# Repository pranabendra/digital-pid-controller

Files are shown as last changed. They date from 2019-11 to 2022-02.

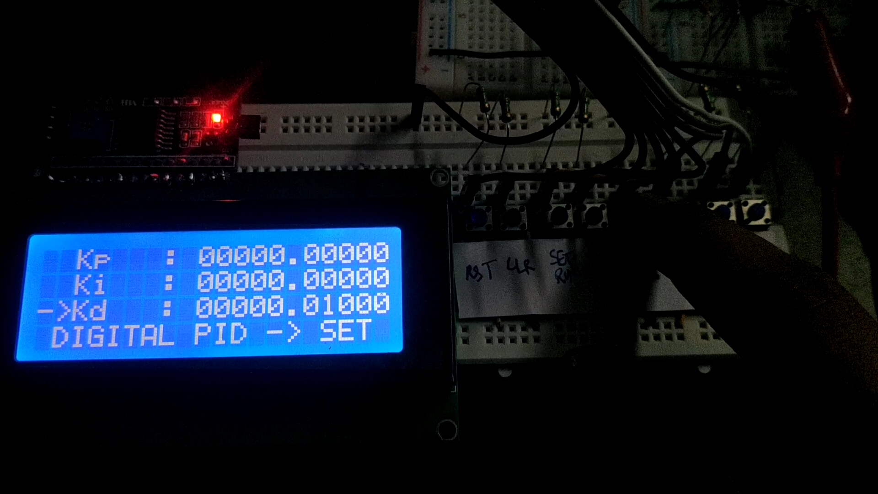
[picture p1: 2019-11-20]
Experiment Pictures/Screenshot_2019-11-15-21-35-13.jpg

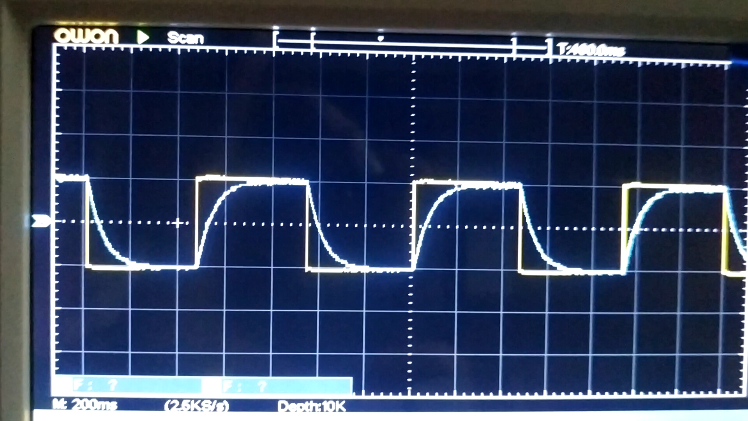
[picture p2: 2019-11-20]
Experiment Pictures/Screenshot_2019-11-15-23-25-31.jpg

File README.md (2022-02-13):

# Digital PID Controller for laboratory usage (Arduino based)

### Control Systems Seminar(I) Project 

<b>Project Title  :</b> Designing a PID controller having analog input and analog output, using digital and analog components for laboratory use

<b>Project Report :</b> [Link](https://github.com/pranabendra/digital-pid-controller/blob/master/Report/Control_Seminar_Project_PPC.pdf)

<b>Project Video  :</b> https://youtu.be/duWAQ8FL80s

---

### Published Paper

<b>Paper Title  :</b> A Framework for Digital PID Controller for Undergraduate Control Systems Laboratory Usage

<b>Paper Link   :</b> [DOI: 10.1109/INDICON52576.2021.9691674](https://doi.org/10.1109/INDICON52576.2021.9691674)

---

### Future work

Improvements can definitely be made to this framework, such as - 
1. A microcontroller having an in-built DAC (such as Arduino Due) can be used. This will eliminate the passive RC filter bank. But, we have to keep in mind that the current system is 5V tolerant. If we use a 3.3V tolerant microcontroller, the system needs a little re-design.
2. One SMPS with an inverting buck boost converter can be used instead of two SMPS. This is just to match the two power rails as close as possible in terms of DC level and ripple factor.
3. Anti-integral windup.
4. Anti-derivative kick. 

---

### Citation

```
@inproceedings{chandra2021framework,
  title={A Framework for Digital PID Controller for Undergraduate Control Systems Laboratory Usage},
  author={Chandra, Pranabendra Prasad},
  booktitle={2021 IEEE 18th India Council International Conference (INDICON)},
  pages={1--7},
  year={2021},
  organization={IEEE}
}
```

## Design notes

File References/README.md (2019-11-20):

# References

1.	Shinskey, F.G., 1979. Process control systems. McGraw-Hill, Inc.. 

2.	Johnson, C.D., 1999. Process control instrumentation technology. Prentice Hall PTR. 

3.	Boylestad, R.L. and Nashelsky, L., 2012. Electronic devices and circuit theory. Prentice Hall. 

4.	Carter, B. and Brown, T.R., 2001. Handbook of operational amplifier applications. Dallas, Tex, USA: Texas Instruments. 

5.	Shirriff, K. and Badger, P., 2009. Secrets of Arduino PWM. Ken Shirriff's Blog. 

6.	How to control a character I2C LCD with Arduino by Benne de Bakker, 
https://www.makerguides.com/character-i2c-lcd-arduino-tutorial/ 

7.	Wikipedia contributors, "PID controller," Wikipedia, The Free Encyclopedia, https://en.wikipedia.org/w/index.php?title=PID_controller&oldid=925590136 (accessed November 15, 2019). 

8.	Arduino Forum, “PWM Frequency Library”, https://forum.arduino.cc/index.php/topic,117425.0.html

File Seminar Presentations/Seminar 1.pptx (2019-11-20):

## Designing a PID controller with analog input and analog output signals using digital and analog components for laboratory use

Pranabendra Prasad Chandra
001610801122

## Block Diagram of a PID controller in a loop

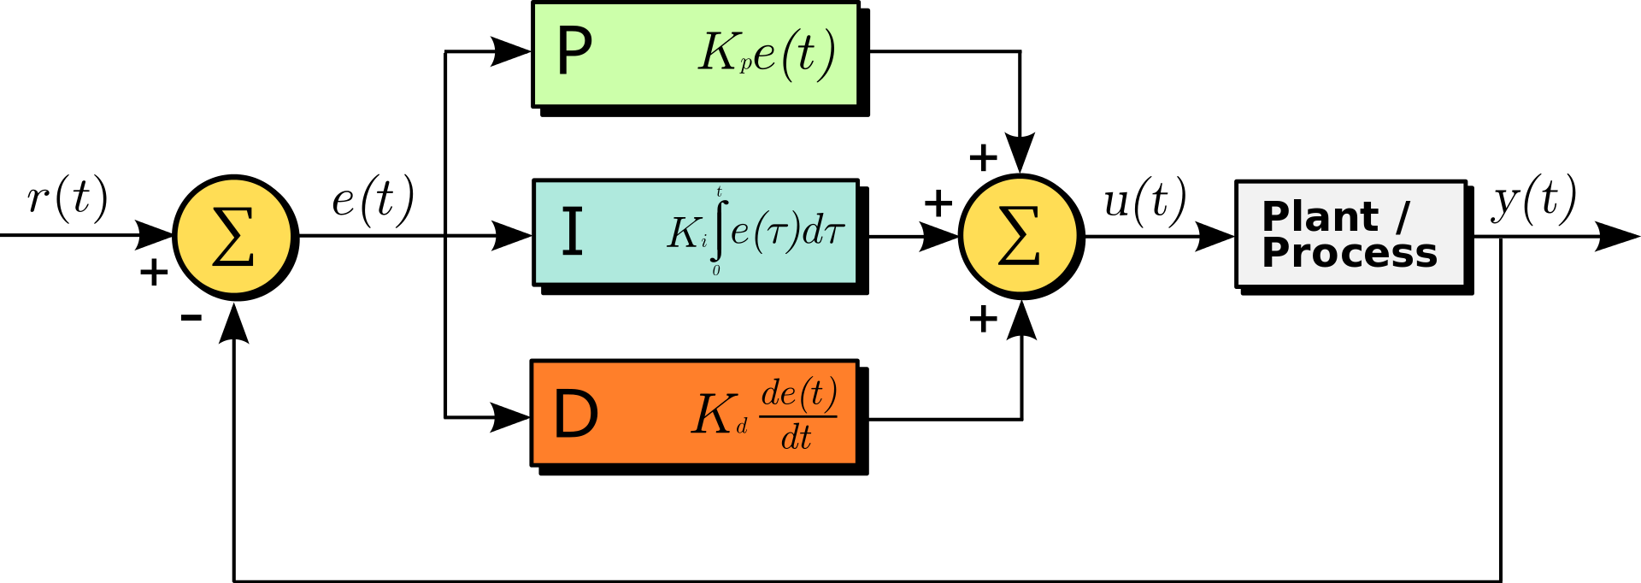
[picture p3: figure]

Image Source: PID Controller – Wikipedia (Link (https://en.wikipedia.org/wiki/PID_controller))

## PID Equation in Continuous Time

In continuous time domain, the PID equation is given as,
Where,
m(t) = controller output
e(t) = error signal

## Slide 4

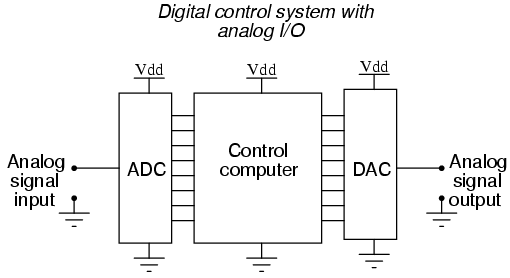
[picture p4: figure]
Image result for adc controller output

Image Source: DAC – All About Circuits (Link (https://www.allaboutcircuits.com/textbook/digital/chpt-13/digital-analog-conversion/))

## Digital Controller Equations

- Let the sampling frequency be fs
- Therefore, the sampling time becomes, τ = 1/ fs
- Replacing t by nτ , in discrete domain, the PID equation becomes

Trapezoidal Integration

Backward Difference

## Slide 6

## Design Specifications

- Maximum voltage input = 230V AC, ±340V DC
- Sampling frequency = Maximum 9 kHz in Arduino Uno (Will try ESP-32)

## Block Diagram

## Rectifier and Attenuator

## References

- Digital Controller Notes by Anjan Rakshit and Amitava Chatterjee
- Mohan, N., Undeland, T.M. and Robbins, W.P., 2003. Power electronics: converters, applications, and design. John wiley & sons.
- Shinskey, F.G., 1979. Process control systems. McGraw-Hill, Inc..

Tools used

Proteus 8 (Circuit Schematic Diagram)
Latex2PNG (Writing Equations)
Draw.io (Block Diagram)

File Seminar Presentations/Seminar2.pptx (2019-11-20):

## Designing a PID controller using analog input and analog output signals using digital and analog components for laboratory use

Pranabendra Prasad Chandra
001610801122

## Top View of the Controller

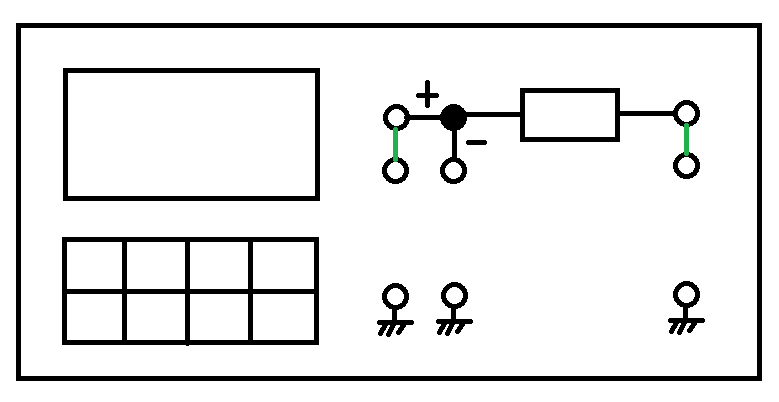
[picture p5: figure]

SET
POINT

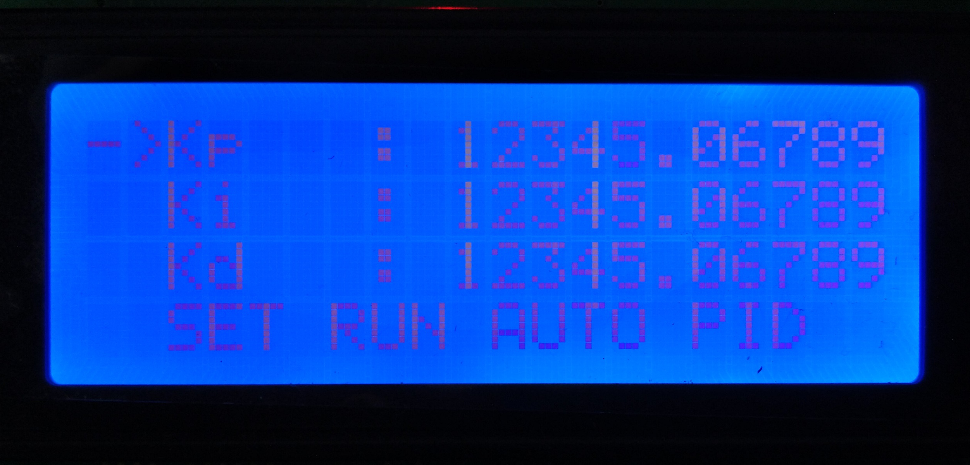
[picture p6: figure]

CONTROLLER

TO PLANT

SCOPE

FEEDBACK

SCOPE

## Block diagram of digital PID in hardware

## Simulation Result

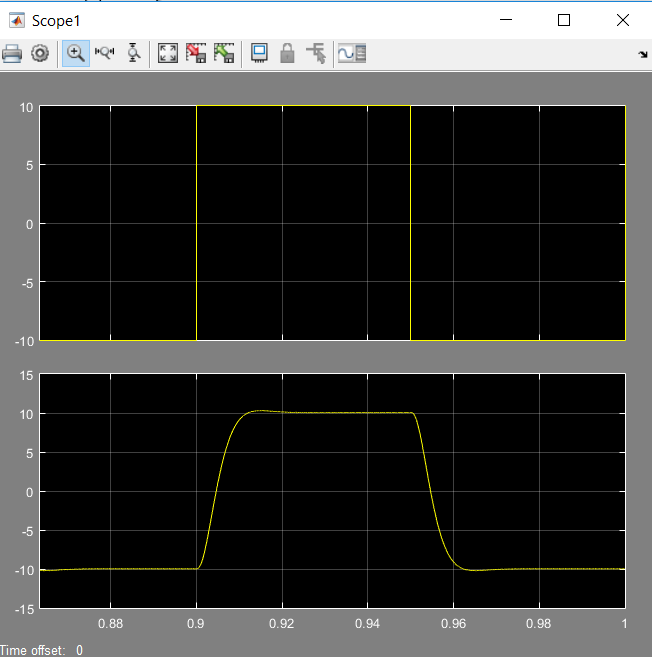
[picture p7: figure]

## Block diagram of digital PID in hardware

## Block diagram of digital PID in hardware

Signal Generator – 10 Vp-p (max)
Sine
Square
Triangle

## Block diagram of digital PID in hardware

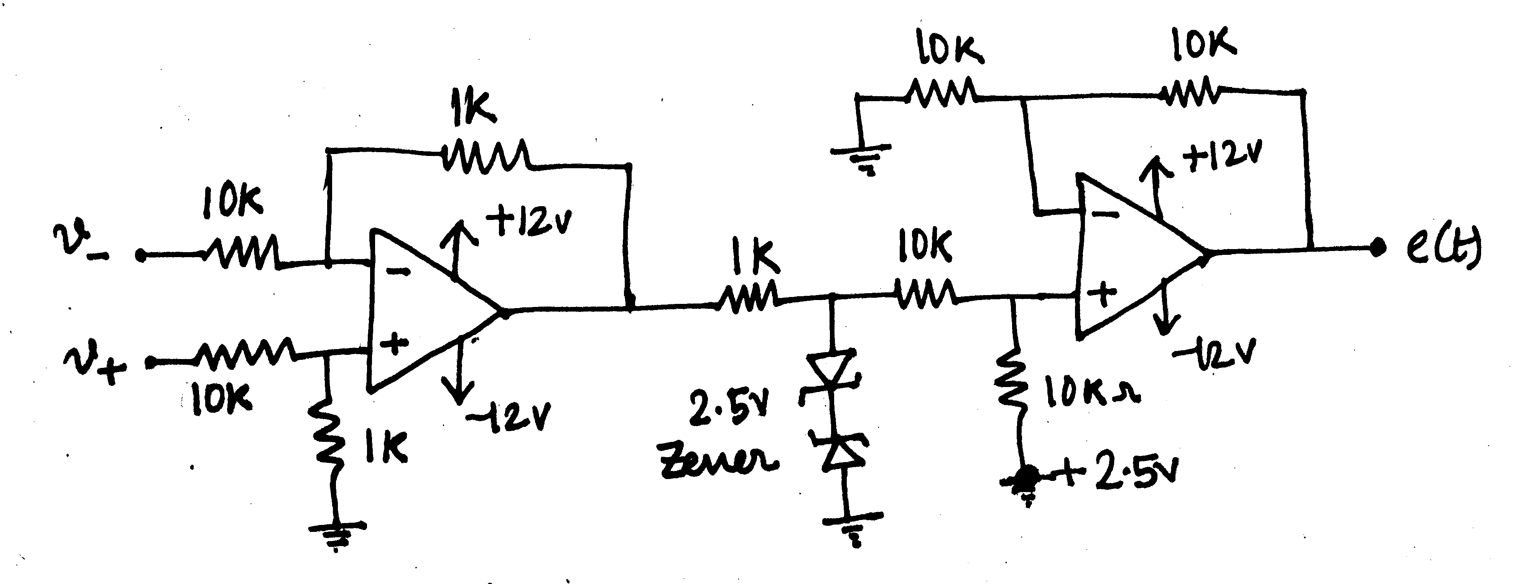
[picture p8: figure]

V- : 10 Vp-p
V+ : 10 Vp-p
e(t) : 0-5V
Op amp : OP07
2.5V Zener : 1N5222B

## Block diagram of digital PID in hardware

5V PWM

20x4 LCD

Keypad

Microcontroller : Arduino Mega
Voltage Input : 5V Regulated DC
Sampling Frequency : 5000 Hz (max 9 kHz)
PWM Switching Frequency : 5000 Hz

## Block diagram of digital PID in hardware

Low Pass Filter
Cut-off frequency should be less than the switching frequency
But, cut-off frequency should be high enough to pass the setpoint
Here, cut-off frequency is 160 Hz (tuneable)

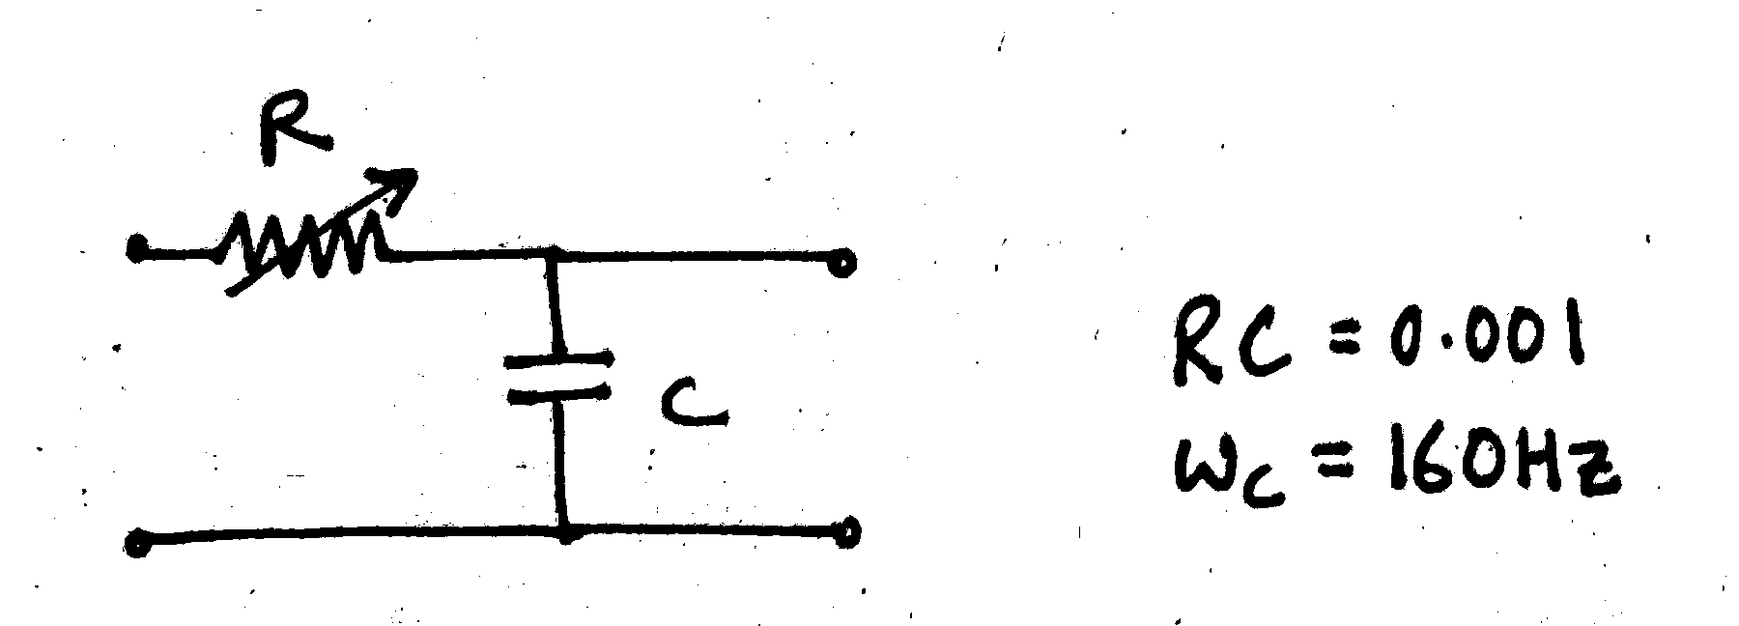
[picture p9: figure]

## Block diagram of digital PID in hardware

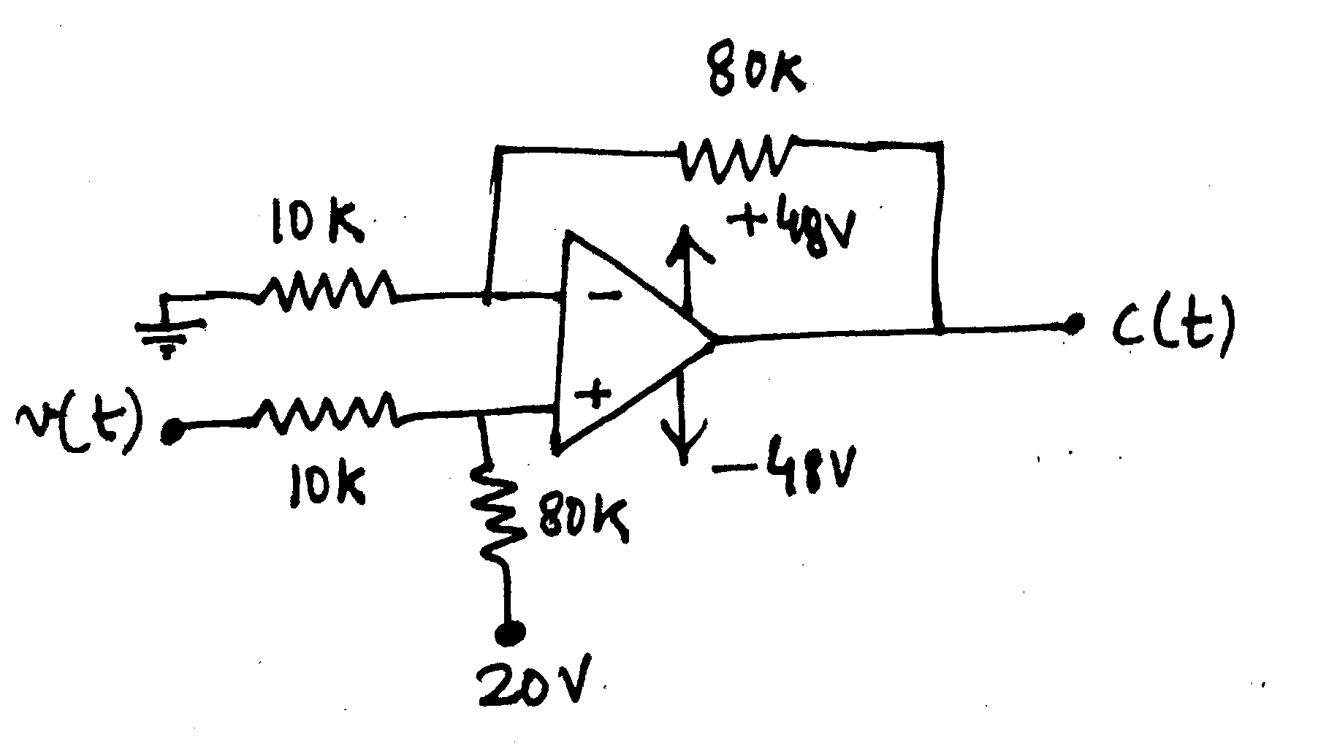
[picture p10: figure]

## Power Lines

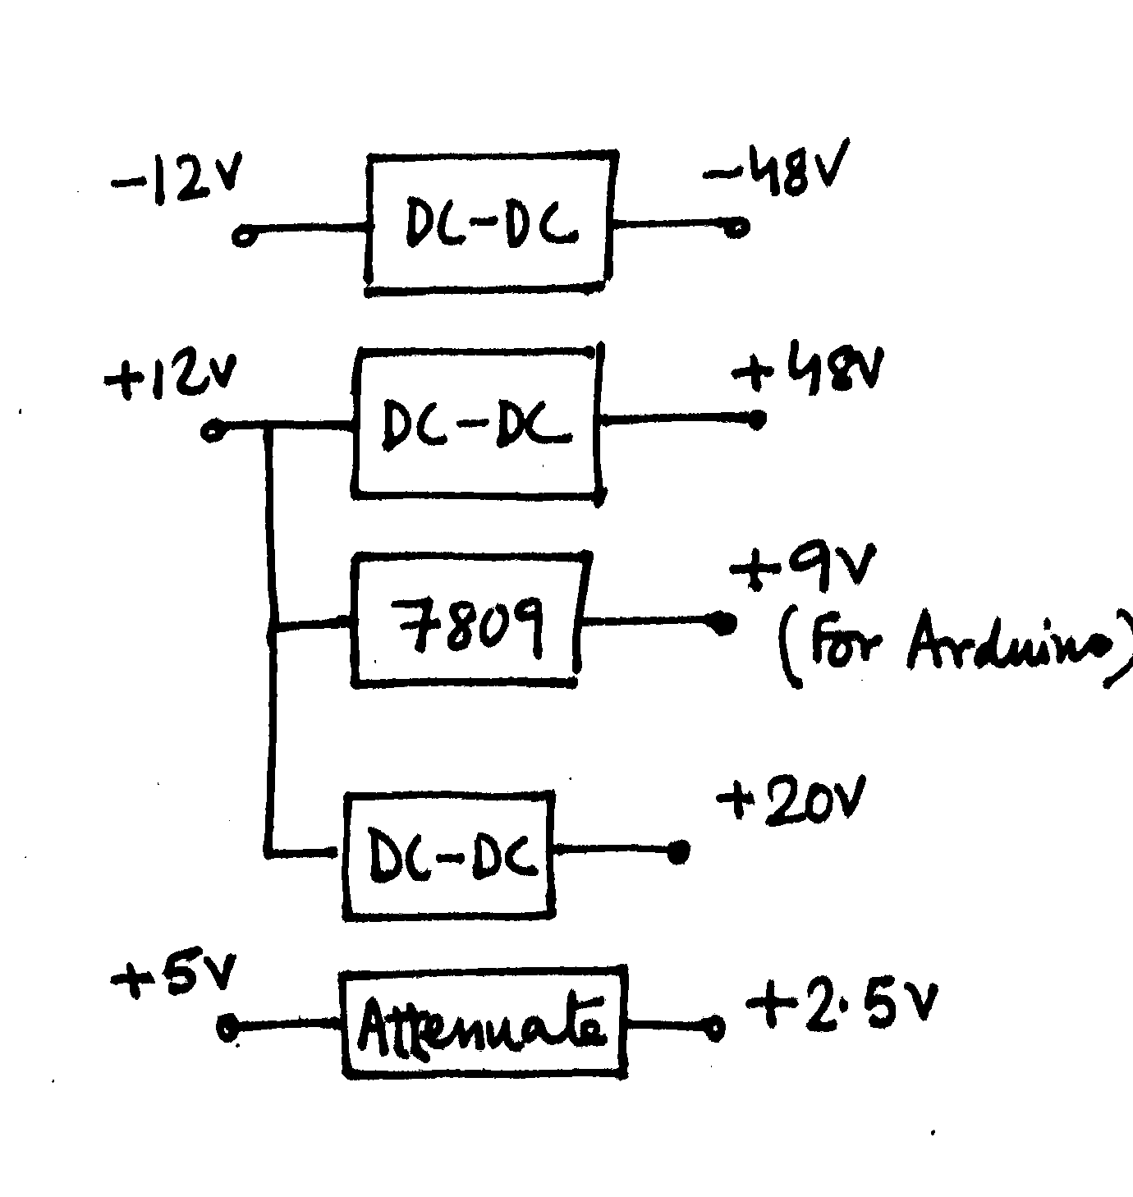
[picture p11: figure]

## Protection

- Risk

- Chance of pressing multiple buttons together
- Shorting the output
- Putting input signal in output port
- Overvoltage in mains
- Overcurrent from mains

- Remedy

- Latching the first button pressed
- Current limiting resistor
- Buffer
- P.T. + Relay
- C.T. + Relay

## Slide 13

## References

- Secrets of Arduino PWM (Link (https://www.arduino.cc/en/Tutorial/SecretsOfArduinoPWM))
- Basic Calculation of an Inverting Buck-Boost Power Stage – Texas Instruments (Link (http://www.ti.com/lit/an/slva721a/slva721a.pdf))

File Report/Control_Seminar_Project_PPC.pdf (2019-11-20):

# DESIGNING A PID CONTROLLER USING ANALOG INPUT AND ANALOG OUTPUT SIGNALS USING DIGITAL AND ANALOG COMPONENTS FOR LABORATORY USE

NOVEMBER 16, 2019
PRANABENDRA PRASAD CHANDRA BEE – IV, Section B2
Roll No. 001610801122

PRANABENDRA PRASAD CHANDRA, BEE-IV, SECTION B2, 001610801122 | 1

## Acknowledgement

The success and final outcome of this project required a lot of guidance and assistance from many people and I am extremely privileged to have got this all along the completion of my project. All that I have done, is only due to such supervision and assistance and I would not forget to thank them.

I wish to express my heartfelt gratitude to my parents, for their encouragement, moral support and care.

I am obliged and grateful to my professors Prof. T.K. Ghoshal, Prof. S. Bhattacharya and Prof.
S. Sadhu for providing me the opportunity to complete a project work on the topic ‘Designing a PID controller using analog input and analog output signals using digital and analog components for laboratory use’. I also wish to express my gratitude to them for their constant support and guidance throughout the work.

This project helped me to understand digital PID controller and its thorough functioning. It also provided me an opportunity for self-learning and know how both hardware and software play equally important rolesin the development of the product.

Also, I would like to extend my sincere thanks to all my classmates for their constant help throughout the work.

Pranabendra Prasad Chandra

PRANABENDRA PRASAD CHANDRA, BEE-IV, SECTION B2, 001610801122 | 2

## Contents

PRANABENDRA PRASAD CHANDRA, BEE-IV, SECTION B2, 001610801122 | 3

## ABSTRACT

Project Topic :

Designing a PID controller using analog input and analog output signals using digital and analog components for laboratory use

PID controllers can be used to regulate flow, temperature, pressure, level, and many other industrial process variables.

This project deals with the development of a digital PID controller for laboratory use. The controller takes in analog signal input, does the computations digitally and then outputs analog signal for the plant. The user operating this controller, can see the PID gains and adjust them as desired. Protections like overvoltage protection and latching of inputs have been incorporated, as a safety measure.

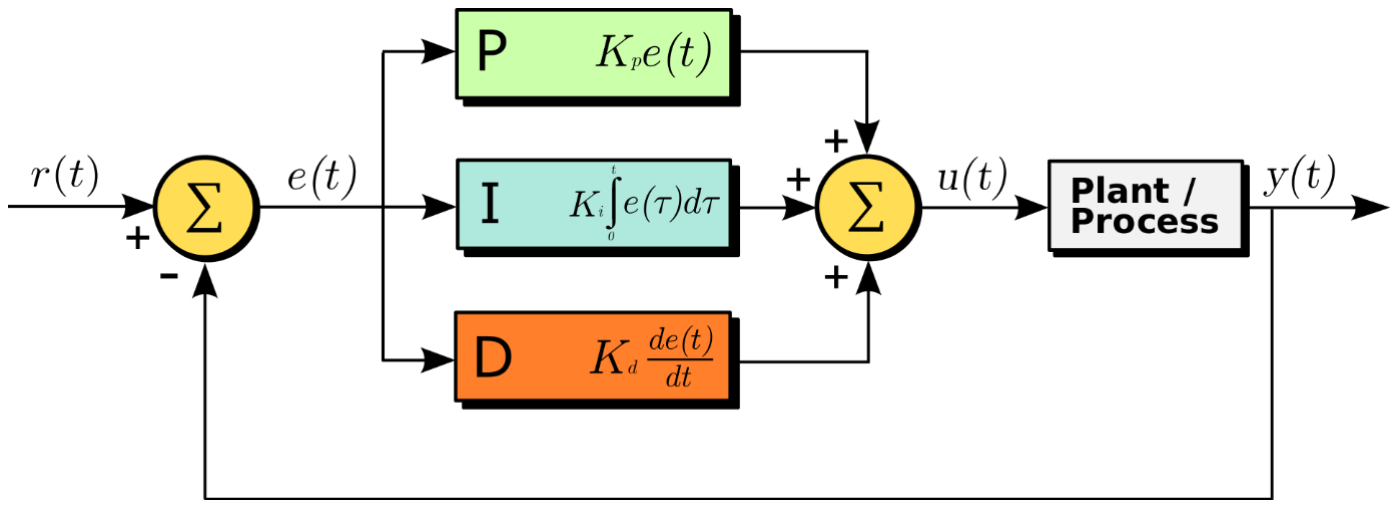
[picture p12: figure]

PRANABENDRA PRASAD CHANDRA, BEE-IV, SECTION B2, 001610801122 | 4

## PID Controller

A PID controller calculates an error value e as the difference between a desired setpoint r and a measured process variable y. It then applies a correction based on the proportional, integral, and derivative terms. Hence, it enables automatic control.

^ Image source: “PID controller overview” by Arturo Urquizo, PID Controller - Wikipedia

PID in continuous-time domain
In continuous time domain, the PID equation is given as,

u(t) = Kpe(t) + Ki ∫ e(τ)dτ

t

0

+ Kd

d
dt e(t)

where,

- e(t) is controller input
- u(t) is controller output
- Kp is proportional gain
- Ki

is integral gain
- Kd is derivative gain

In Laplace domain, the PID operation can be represented as,

e(t) | u(t)
PID(s)

PRANABENDRA PRASAD CHANDRA, BEE-IV, SECTION B2, 001610801122 | 5

PID in discrete-time domain

Let, the sampling frequency be fs

∴ Sampling time period = Ts = 1/fs

Discretizing the continuous time domain PID equation,

u(t) = Kpe(t) + Ki ∫ e(τ)dτ

t

0

+ Kd

d
dt e(t)

un = Kpen + KiTs∑ ej

n−1

j=0

+

Kd
Ts

(en − en−1)

Since we have tried to simulate the digital PID controller in Simulink first, we have followed the transfer function offered by Simulink, all throughout the project.

The Discrete PID Controller block in Simulink, MATLAB has the transfer function,

U(z)
E(z)

= Kp + KiTs

1
z − 1

+ Kd

N

1 + NTs

1
z − 1

Converting this transfer into difference equations, we obtain,

- un
(1) = Kp en
- un
(2) = un−1
(2) + KiTsen−1
- un
(3) = un−1

(3)
(1 − NTs

) + DN(en − en−1

)

Summing these three difference equations, the controller output becomes

un = un

(1) + un
(2) + un

(3)

The filter coefficient N in the above transfer function implements derivative action, by forming a proper transfer function. If N is sufficiently large, the derivative term will tend to

Kd
Ts

(z − 1)

en | un
PID(z)
A/D Converter | D/A Converter
e(t) | u(t)

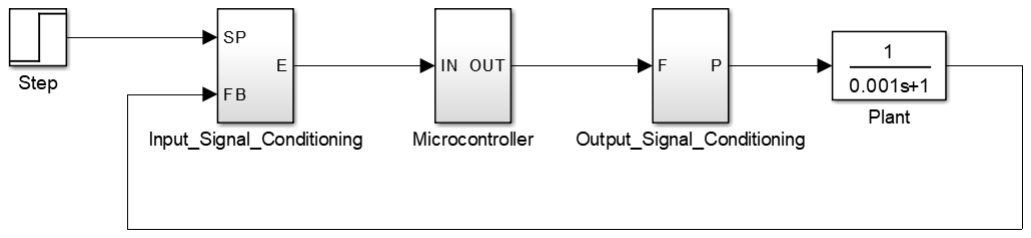
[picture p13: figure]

PRANABENDRA PRASAD CHANDRA, BEE-IV, SECTION B2, 001610801122 | 6

## Implementation

Controller Specifications
Supply voltage +12V and -12V (generated using two SMPS)

Voltage of input signal and feedback should be within +10V to -10V

Sampling frequency = 5000 Hz

PWM switching frequency = 100 kHz
Block Diagram and Simulation in Simulink
SP | : | Set Point
FB | : | Feedback (Plant Output)
E | : | Modified Error
IN | : | Microcontroller Signal Input
OUT | : | Microcontroller Signal Output (PWM)
F | : | Filter Input
P | : | Plant Input (Controller Output)

Input Signal Conditioning
As mentioned in the controller specifications, | −10V ≤ VSP,VFB ≤ 10V
Hence, | −20V ≤ (VSP − VFB) ≤ 20V

Modified error E =

VSP−VFB
10

+ 2.5V

Therefore, 0.5V ≤ E ≤ 4.5V

This bound of E ensures that the ADC of the microcontroller does not get damaged, as it can only take positive voltages less than or equal to 5V.

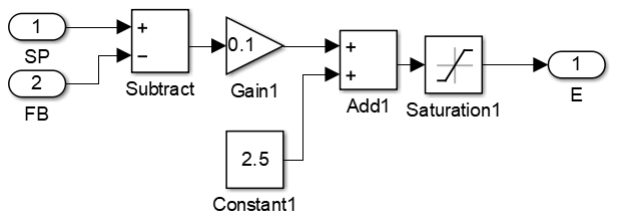
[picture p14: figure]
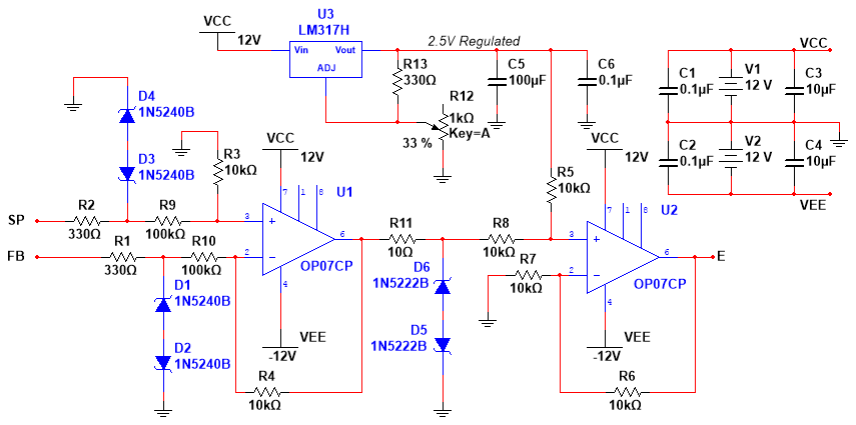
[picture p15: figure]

PRANABENDRA PRASAD CHANDRA, BEE-IV, SECTION B2, 001610801122 | 7

Circuit Realisation

- U1 and U2 are precision op-amps, having very low offset voltage, in the order of microvolts.
- U1 acts as a differential amplifier having gain 0.1 to attenuate (VSP – VFB) by 10 times. D1 and D2 are used in back-to-back mode for overvoltage protection. Their breakdown voltage is 10V. This ensures that the signal passing through to R10 remains within +10V and -10V. Else, the Zener diodes clips the voltage. R1 is used as a current limiting resistance, to protect D1 and D2 from overcurrent. Similar is the case for D3, D4, R2 and R9.
- D5 and D6 have breakdown voltage of 2.5V. They function similarly, to keep the signal within the limits of -2.5V to +2.5V.
- U3 is an adjustable positive voltage regulator. R12 is adjusted finely, to set the output regulated voltage to 2.5V.
- U2 acts as a non-inverting adder, with gain 1. It generates an offset of 2.5V to the bipolar signal, to make it a unipolar signal (lying between 0V to 5V).
- All the capacitors used in the above circuit, are decoupling capacitors used with voltage supplies.

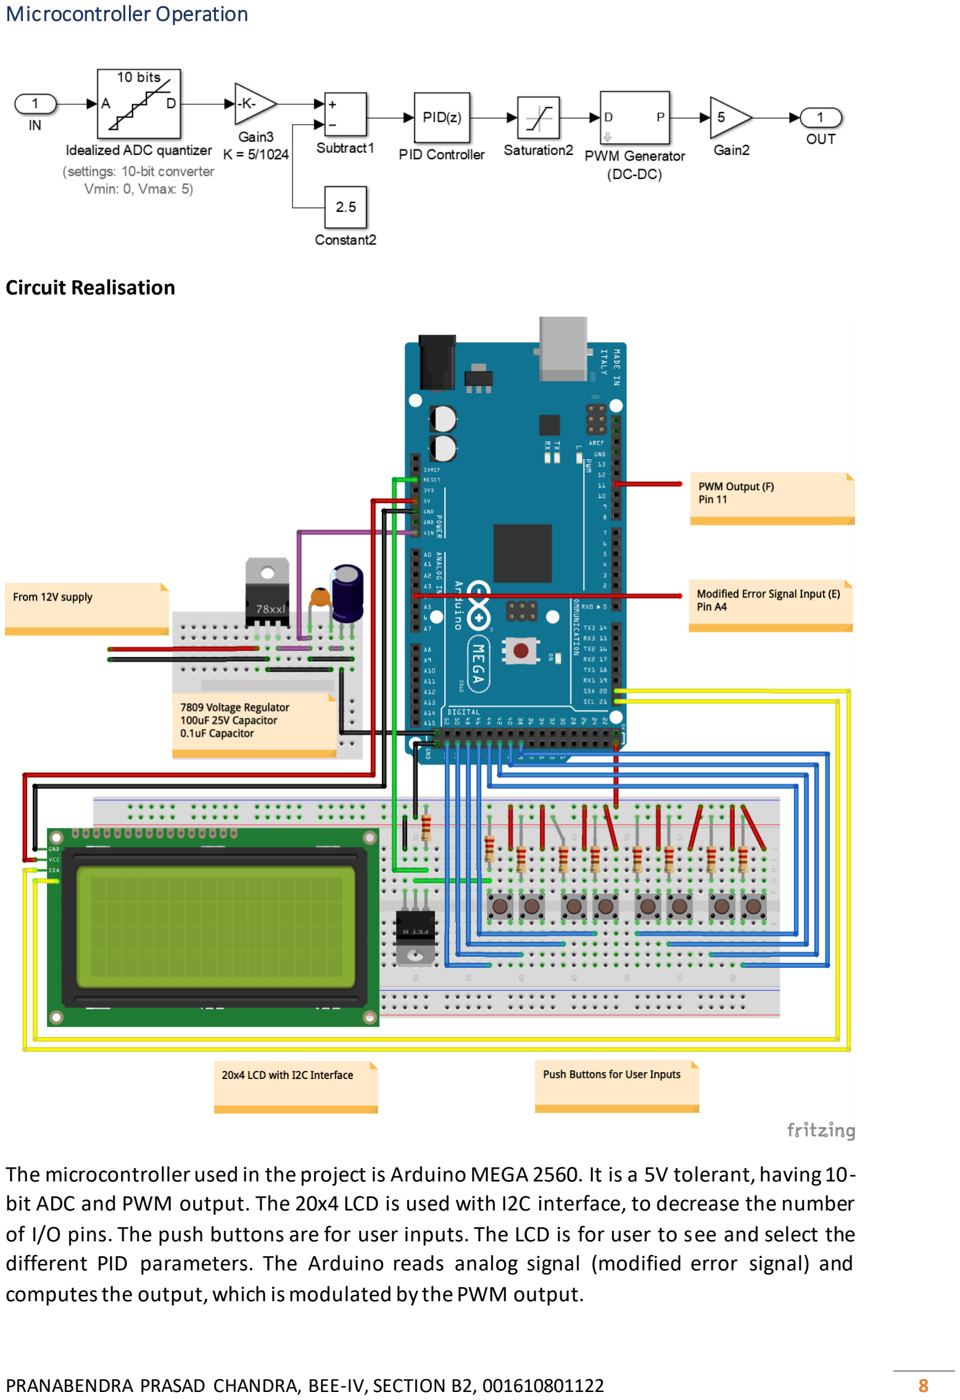
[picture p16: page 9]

PRANABENDRA PRASAD CHANDRA, BEE-IV, SECTION B2, 001610801122 | 8

Microcontroller Operation

Circuit Realisation

The microcontroller used in the project is Arduino MEGA 2560. It is a 5V tolerant, having 10-bit ADC and PWM output. The 20x4 LCD is used with I2C interface, to decrease the number of I/O pins. The push buttons are for user inputs. The LCD is for user to see and select the different PID parameters. The Arduino reads analog signal (modified error signal) and computes the output, which is modulated by the PWM output.

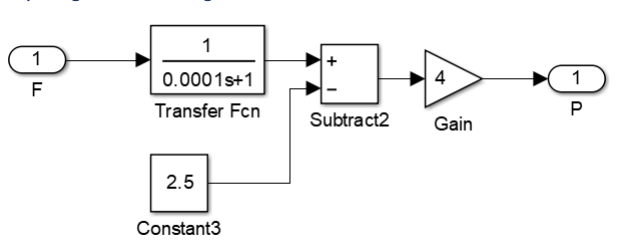
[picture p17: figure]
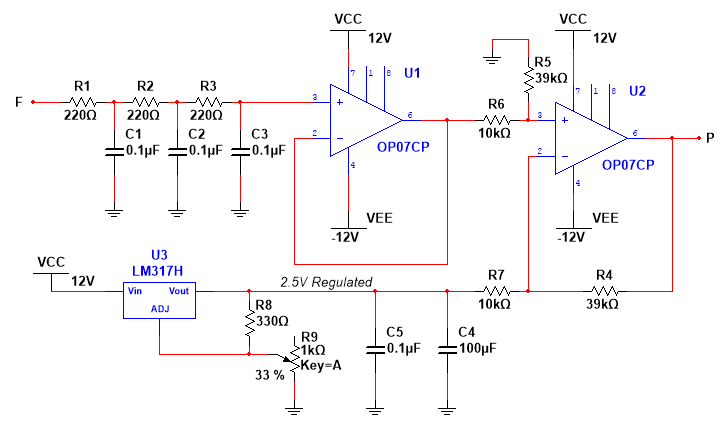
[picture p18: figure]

PRANABENDRA PRASAD CHANDRA, BEE-IV, SECTION B2, 001610801122 | 9

Output Signal Conditioning

Circuit Realisation

- The PWM output from the microcontroller is passed through a three-stage cascaded RC low pass filter (cut-off frequency of approximately 1.5kHz), to obtain the demodulated controller output.
- U1 acts as a buffer to avoid loading effect.
- U2 as a differential amplifier, with gain 3.9 (approx. 4). The demodulated controller output is cleared of any offset, by subtracting 2.5V from it. Therefore, it converts the unipolar signal, to a bipolar signal.
- U3 is an adjustable positive voltage regulator. R12 is adjusted finely, to set the output regulated voltage to 2.5V.
- Capacitors C4 and C5 are used as decoupling capacitors along with the voltage supply.

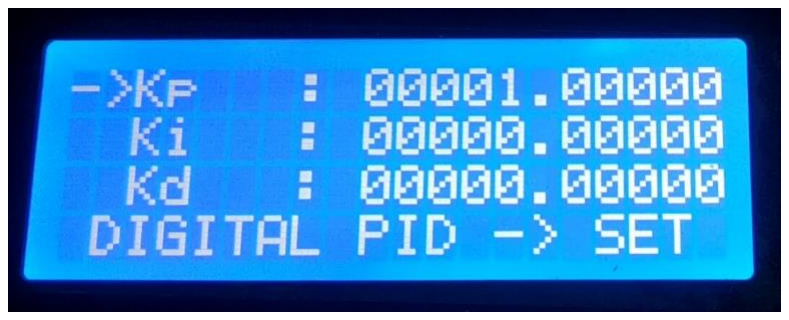
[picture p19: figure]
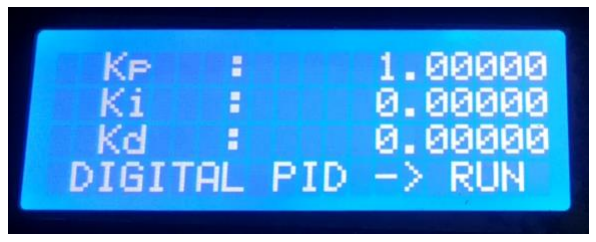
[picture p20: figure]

PRANABENDRA PRASAD CHANDRA, BEE-IV, SECTION B2, 001610801122 | 10

## User Interface

LCD

Push Buttons (User Input)

Button Name | Function | SET Mode | RUN Mode
RIGHT | Moves the cursor right | ✔
LEFT | Moves the cursor left | ✔
UP | Increments the current digit MOD 10 | ✔
DOWN | Decrements the current digit MOD 10 | ✔
SELECT | Selects parameter (Kp, Ki, Kd) to be set | ✔
SET/RUN | To change parameter value and update to run | ✔ | ✔
CLEAR | Clears the parameter value to all zeros | ✔
RESET | Resets the microcontroller | ✔ | ✔
SET Mode | RUN Mode
SELECT | UP DOWN | LEFT RIGHT SET

## RUN

## RESET CLEAR

PRANABENDRA PRASAD CHANDRA, BEE-IV, SECTION B2, 001610801122 | 11

## Software Routines

Reading the states of the push buttons
Whenever the program enters void loop() the states of the eight push buttons are read and stored. If any button is pressed, the microcontroller will read HIGH, else it will read LOW.

Latching of button press
Whenever a button is pressed, it will be latched, but no HIGH state will be registered. During that time, if any other button is pressed, they will not be active to register their states. Only when the initial button is released, the falling edge is detected and HIGH is registered for that particular button only.

Detecting which button is pressed
From the previous state and the present state of push buttons, the button that is pressed, is detected. For that particular button, necessary action as a result of the button press.

Display LCD in SET mode
When the controller is in SET mode, the parameter pointer blinks and the cursor blinks for the user to change or update the value.

Display LCD in RUN mode
When the controller is in RUN mode, the LCD becomes static and shows the current value of the parameters.

Reading the error value
The modified error signal is read and the offset is removed to get the attenuated error value.

Computing the controller output
The previous controller output, the present sample and the previous sample of the error is passed through a set of difference equations to obtain the current controller output.

Changing the duty cycle of PWM
The current controller output value determines the duty cycle of the PWM, which is always running at constant switching frequency.

## Experimental Setup

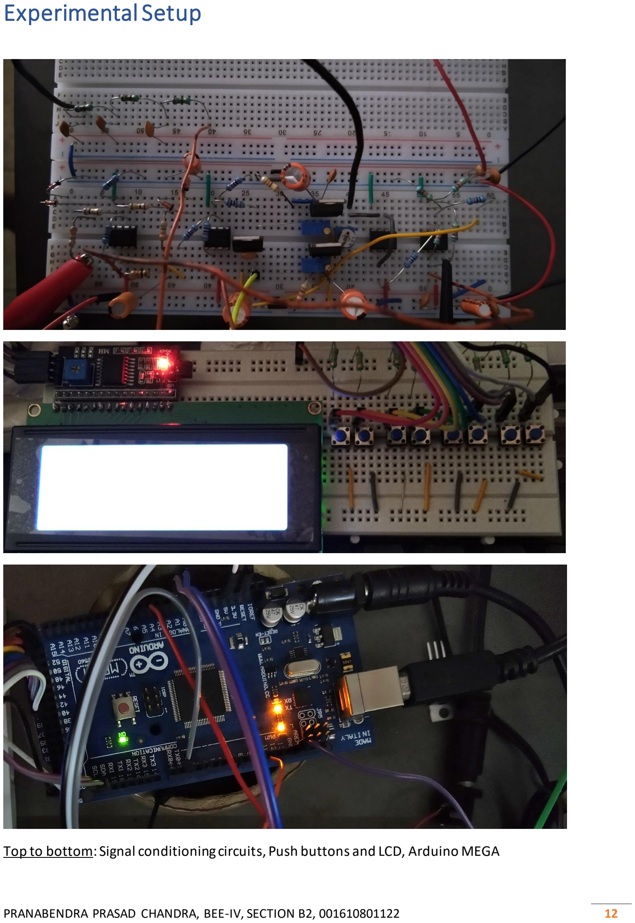
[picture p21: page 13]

PRANABENDRA PRASAD CHANDRA, BEE-IV, SECTION B2, 001610801122 | 12

Top to bottom: Signal conditioning circuits, Push buttons and LCD, Arduino MEGA

## Result

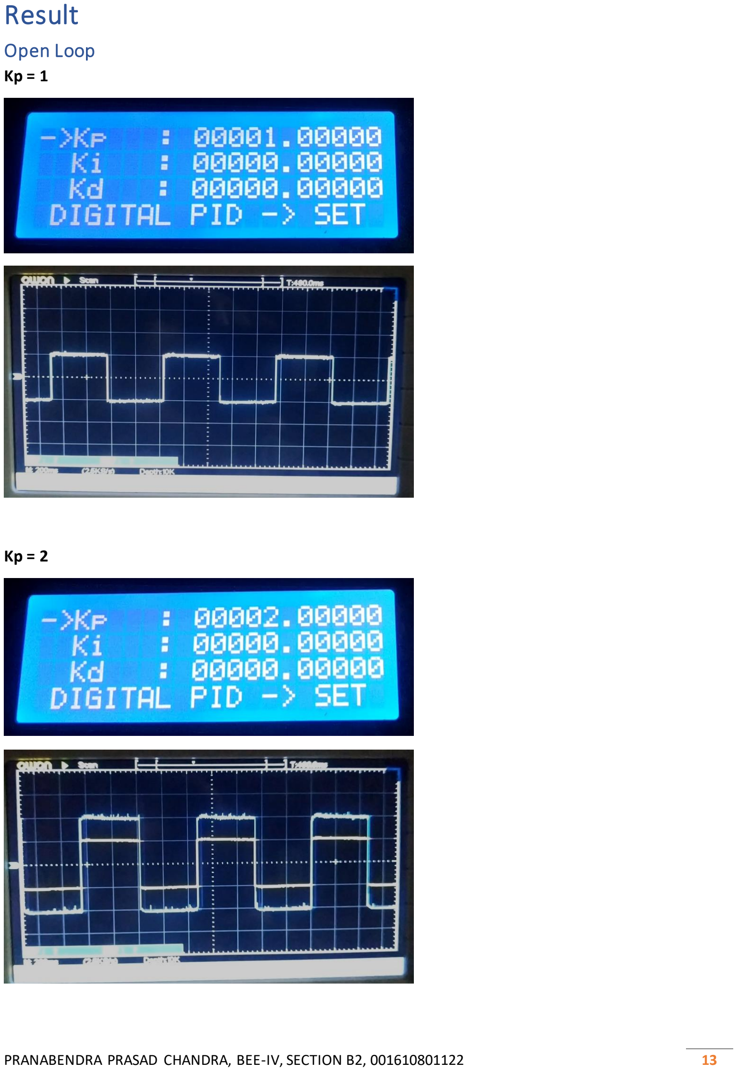
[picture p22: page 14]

PRANABENDRA PRASAD CHANDRA, BEE-IV, SECTION B2, 001610801122 | 13

Open Loop
Kp = 1

Kp = 2

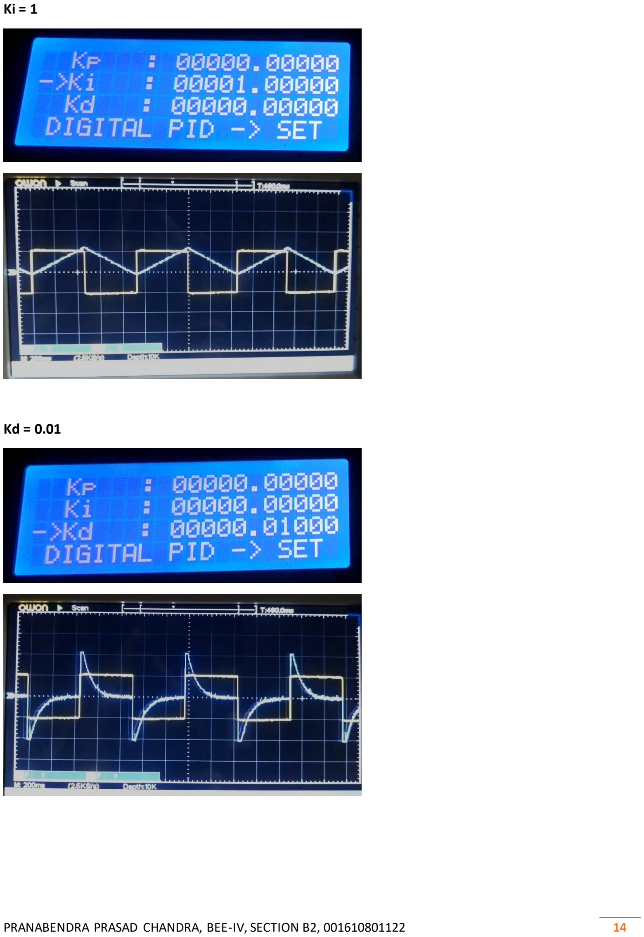
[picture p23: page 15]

PRANABENDRA PRASAD CHANDRA, BEE-IV, SECTION B2, 001610801122 | 14

Ki = 1

Kd = 0.01

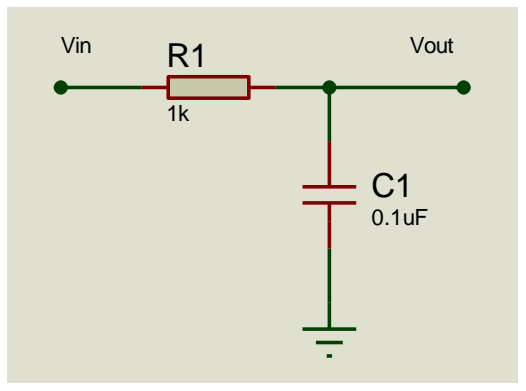
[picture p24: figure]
Vin; Vout
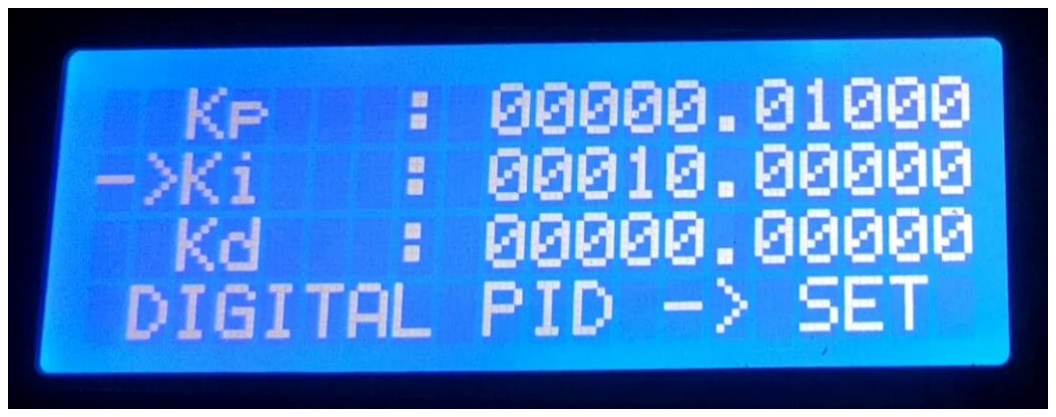
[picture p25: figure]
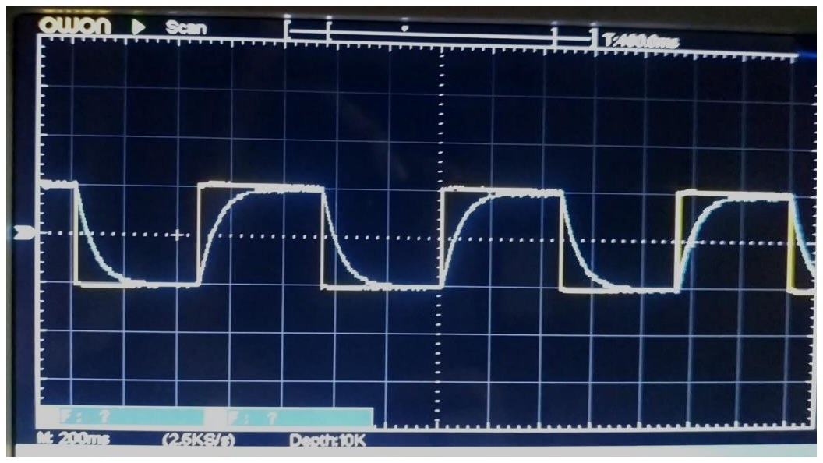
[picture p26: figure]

PRANABENDRA PRASAD CHANDRA, BEE-IV, SECTION B2, 001610801122 | 15

Closed Loop

Plant

Plant Transfer Function ∶

1
0.0001s + 1

Kp = 0.01, Ki = 10 (PI control)

FRONT VIEW; RESET; SELECT; CLEAR; SET RUN; CONTROLLER; SET POINT; FEEDBACK

PRANABENDRA PRASAD CHANDRA, BEE-IV, SECTION B2, 001610801122 | 16

## Proposed Box Design

## Conclusion

1. Due to the use of passive RC filter to demodulate the controller output from PWM, the controller performs poorly if the set point signal frequency becomes comparable to the cut off frequency of the filter. Also, the system time constant increases slightly. These effects can be eliminated, if a microcontroller with an inbuilt DAC is used.
2. This digital PID controller works as desired for low frequencies (<= 100 Hz).
3. The controller is the amalgamation of both hardware and software, giving desired output asset by user via the user interface.

PRANABENDRA PRASAD CHANDRA, BEE-IV, SECTION B2, 001610801122 | 17

## References

- Shinskey, F.G., 1979. Process control systems. McGraw-Hill, Inc..
- Johnson, C.D., 1999. Process control instrumentation technology. Prentice Hall PTR.
- Boylestad, R.L. and Nashelsky, L., 2012. Electronic devices and circuit theory. Prentice Hall.
- Carter, B. and Brown, T.R., 2001. Handbook of operational amplifier applications. Dallas, Tex, USA: Texas Instruments.
- Shirriff, K. and Badger, P., 2009. Secrets of Arduino PWM. Ken Shirriff's Blog.
- How to control a character I2C LCD with Arduino by Benne de Bakker https://www.makerguides.com/character-i2c-lcd-arduino-tutorial/
- Wikipedia contributors, "PID controller," Wikipedia, The Free
Encyclopedia, https://en.wikipedia.org/w/index.php?title=PID_controller&oldid=925 590136 (https://en.wikipedia.org/w/index.php?title=PID_controller&oldid=925590136) (accessed November 15, 2019).
- Arduino Forum, “PWM Frequency Library”, https://forum.arduino.cc/index.php/topic,117425.0.html

PRANABENDRA PRASAD CHANDRA, BEE-IV, SECTION B2, 001610801122 | 18

## Appendix

List of Components Used

Component Type | Component Name | Functions
Microcontroller | Arduino Mega 2560 (Rev 3) | Processing unit
SMPS | 12V, 1A | Voltage Source
LCD Module | 20x4 | LCD Display
I2C Interface for LCD | I2C Module | To reduce LCD I/O
Precision Op Amp | OP07 | Very low input offset voltage
Constant Voltage Regulator | 7809 | To power Arduino
Variable Voltage Regulator | LM317 | To generate offset
Zener Diodes | 1N5240B, 1N5222B | Overvoltage protection
N Channel MOSFET | BS170 | Switch to reset Arduino
Push Buttons | 1825910-7 | To take user inputs
Resistors | 10, 220, 330, 1k, 10k, 100k, 39k (all in Ω)
Potentiometers | 1k Trim pot | For accurate setting of voltage
Capacitors | 0.1, 10, 100 (all in µF)

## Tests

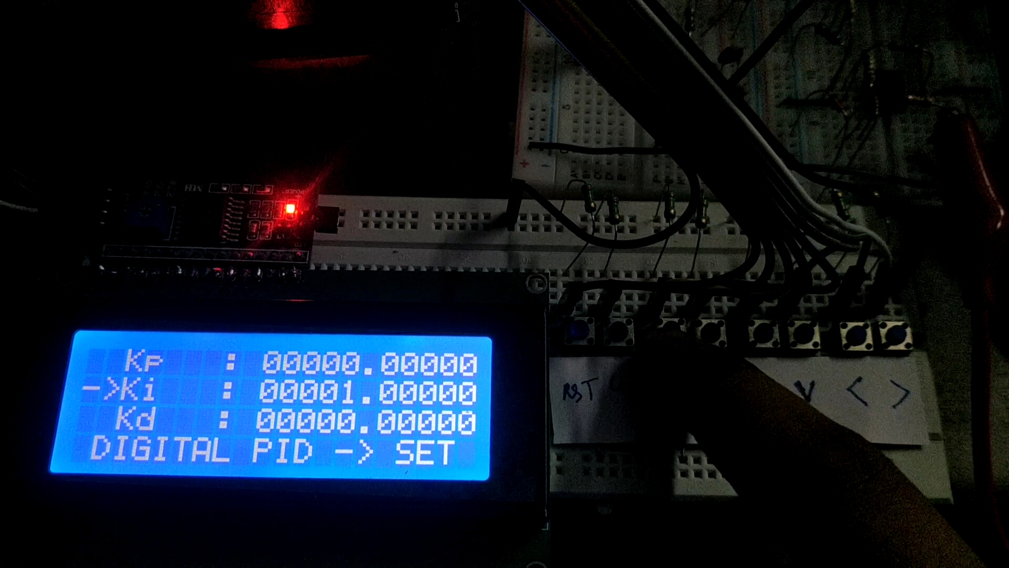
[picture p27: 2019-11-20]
Experiment Pictures/Screenshot_2019-11-15-21-33-38.jpg

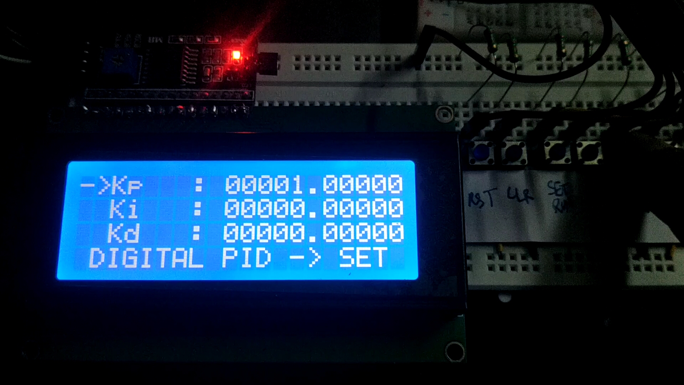
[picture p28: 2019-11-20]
Experiment Pictures/Screenshot_2019-11-15-19-36-00.jpg

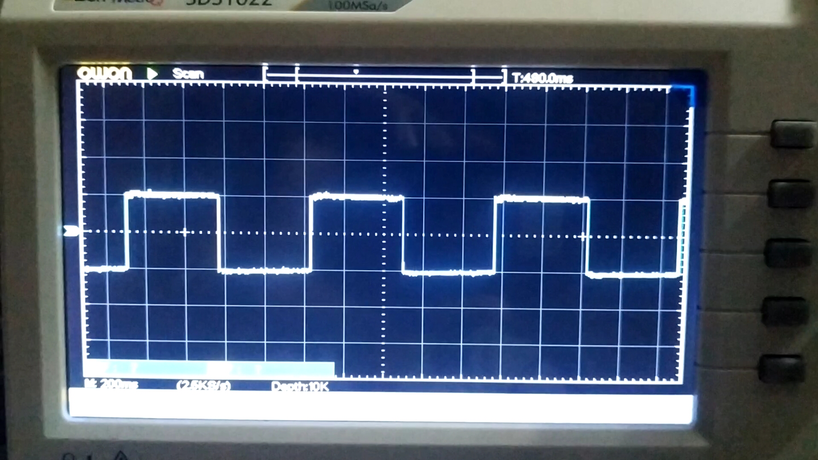
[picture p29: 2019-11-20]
Experiment Pictures/Screenshot_2019-11-15-21-30-53.jpg

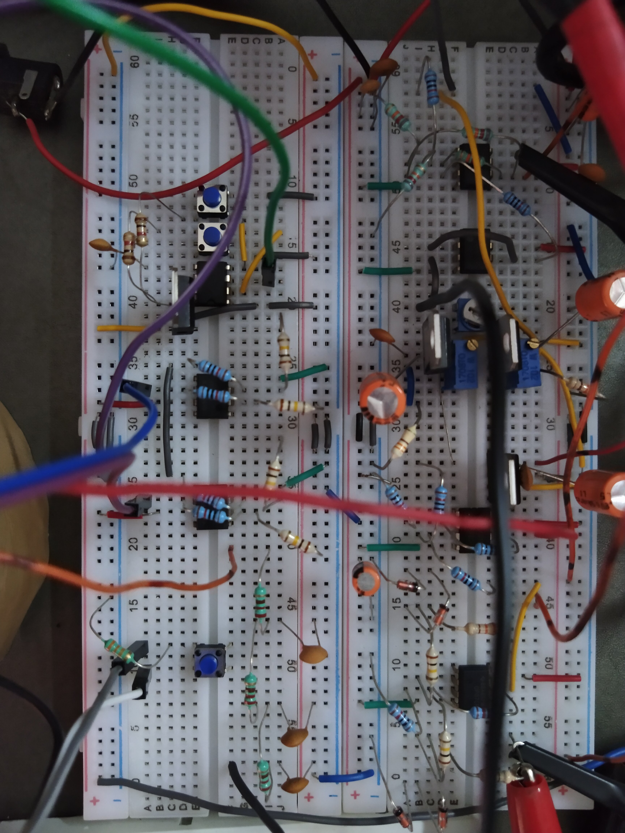
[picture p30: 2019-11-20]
Experiment Pictures/IMG_20191108_121813_LL.jpg

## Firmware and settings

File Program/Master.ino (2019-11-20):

#include <Wire.h>
#include <LiquidCrystal_I2C.h>
#include <Arduino.h>
#include "stdlib.h"
#include <PWM.h>
int32_t frequency = 100000;

LiquidCrystal_I2C lcd(0x27, 20, 4);

class Line {
  public:
    String line;
    int cursor_position;
    int decimal_position;
    int lower_limit;
    int upper_limit;
    bool enable;
    char numeric_array_intermediate[10] = {'0', '1', '2', '3', '4', '5', '6','7', '8', '9'};
    char numeric_array_begin[10] = {' ', '1', '2', '3', '4', '5', '6','7', '8', '9'};
    long unsigned int most_significant_number = 4;

    void initialize_line(String init_line) {
      line = init_line;
      cursor_position = 13;

      decimal_position = 14;
      lower_limit = 9;
      upper_limit = 19;
    }

    void select_line() {
      line[0] = '-';
      line[1] = '>';
    }

    void deselect_line() {
      line[0] = ' ';
      line[1] = ' ';
    }

    void clear_number() {
      for(int sub_char = lower_limit; sub_char <= upper_limit; sub_char++)
      {
        if (sub_char != decimal_position) {
          line[sub_char] = '0';
        }
      }
    }

    int get_cursor_position() {
      return cursor_position;
    }

    void move_cursor_right() {
      cursor_position = ((cursor_position + 3) % 11) + 9;
      if (cursor_position == decimal_position) {
        cursor_position++;
      }
    }

    void move_cursor_left() {
      cursor_position = ((cursor_position + 1) % 11) + 9;
      if (cursor_position == decimal_position) {
        cursor_position--;
      }
    }

    void increment_digit() {
      int old_digit = line[cursor_position] - '0';
      line[cursor_position] = numeric_array_intermediate[(old_digit + 1) % 10];
    }

    void decrement_digit() {
      int old_digit = line[cursor_position] - '0';
      line[cursor_position] = numeric_array_intermediate[(old_digit + 9) % 10];
    }

    void encode_string() {
      for(int sub_char = lower_limit; sub_char < decimal_position - 1; sub_char++)
      {
        if (line[sub_char] == ' ')
        {
          line[sub_char] = '0';
        }
      }
    }

    void decode_string() {
      for(int sub_char = lower_limit; sub_char < decimal_position - 1; sub_char++)
      {
        if (line[sub_char] == '0')
        {
          line[sub_char] = ' ';
        }
        else {
          break;
        }
      }
    }

    double get_parameter_value () {
//      String parameter_string_before_decimal = line.substring(lower_limit, decimal_position);
//      String parameter_string_after_decimal = line.substring(decimal_position + 1, upper_limit + 1);
//      // return parameter_string.toFloat();
//      Serial.println(parameter_string_before_decimal);
//      Serial.println(parameter_string_after_decimal);
//      double parameter_value = atoi(parameter_string_before_decimal.c_str()) + 0.00001*atoi(parameter_string_after_decimal.c_str());
//        return parameter_value;
      
      return atof(line.substring(9,19).c_str());
    }  
};

// LCD Parameters
// String line3    = " V WARN SET MAN PID ";
String setPointString = "SET POINT  =       V";
String feedbackString = "FEED BACK  =       V";
String line3    = " DIGITAL PID -> RUN ";
// String line3    = " V WARN SET MAN PID ";
// String line3 = "  SET RUN AUTO PID  ";
String modifiedLine = "";
unsigned long startTime = 0;
bool visited[4] = {false};
int lineNum = 0;
int index = 0;
int presentState = 0;
// String line = "";
int current_line = 0;
bool run_status = 0;

// Keypad Parameters
const int right = 39;
const int left = 41;
const int down = 43;
const int up = 45;
const int select_parameter = 47;
const int set_run = 49;
const int clear_digit = 51;
const int auto_set = 53;

// Voltage Measurement
const int input_signal = A0;
const int feedback_signal = A1;
const int toggle_display = 2;
float input_signal_value;
String input_signal_MSB;
String input_signal_LSB;
float feedback_signal_value;
String feedback_signal_MSB;
String feedback_signal_LSB;

int previous_input[8];
int current_input[8] = {0};
int button_press[8] = {0};

int button;
int button_pins[8] = {right, left, down, up, select_parameter, set_run, clear_digit, auto_set};

bool latch_status = false;
int latch_button = -1;

Line line[3];

// Difference Equation
const int pwm_output = 11;
const int pid_signal_input = A4;
const int status_pin_led = 13;
unsigned long startSamplingTime = 0;
unsigned long boundaryTime = 0;
int val = 0;
float x = 0;

const float V_level = 5.2;
// const float Ts = 0.000125;
const float Ts = 0.0002;
const int N = 100;
float P = 0;
float I = 0;
float D = 0;

float y1_new = 0;
float y1_old = 0;
float y2_new = 0;
float y2_old = 0;
float y3_new = 0;
float y3_old = 0;
float x_new = 0;
float x_old = 0;
float y_new = 0;
float y_old = 0;
float duty_cycle_new = 0;
float duty_cycle_old = 0;
float pid_output = 0;
float duty_cycle = 0;

void setup()
{

  line[0].initialize_line("  Kp   : 00000.00000");
  line[1].initialize_line("  Ki   : 00001.00000");
  line[2].initialize_line("  Kd   : 00000.00000");
  // line[1].initialize_line("  Ti(s): 12345.06789");
  // line[2].initialize_line("  Td(s): 12345.06789");
  line[0].select_line();
  lcd.init();
  lcd.init();
  lcd.backlight();

  lcd.setCursor(0, 0);
  lcd.print(line[0].line);
  lcd.setCursor(0, 1);
  lcd.print(line[1].line);
  lcd.setCursor(0, 2);
  lcd.print(line[2].line);
  lcd.setCursor(0, 3);
  lcd.print(line3);

  pinMode(right, INPUT);
  pinMode(left, INPUT);
  pinMode(down, INPUT);
  pinMode(up, INPUT);
  pinMode(select_parameter, INPUT);
  pinMode(set_run, INPUT);
  pinMode(clear_digit, INPUT);
  pinMode(auto_set, INPUT);

  pinMode(input_signal, INPUT);
  pinMode(toggle_display, INPUT);

  InitTimersSafe();
  bool success = SetPinFrequencySafe(pwm_output, frequency);
  if (success) {
    pinMode(status_pin_led, OUTPUT);
    digitalWrite(status_pin_led, HIGH);
  }
  
  pinMode(pid_signal_input, INPUT);
  
  startSamplingTime = micros();
  boundaryTime = millis();
  
  Serial.begin(115200);
}

void loop()
{
  for (button = 0; button < 8; button++)
  {
    current_input[button] = digitalRead(button_pins[button]);
  }

  for (button = 0; button < 8; button++)
  {
    if (previous_input[button] - current_input[button] == -1 && !latch_status)
    {
      latch_status = true;
      latch_button = button;
    }

    if (latch_status)
    {
      if (button == latch_button)
      {
        button_press[button] = previous_input[button] - current_input[button];
      }
      else
      {
        button_press[button] = 0;
      }

      if (button_press[button] == 1)
      {
        latch_status = false;
      }
    }
  }

  // Begin

  if (button_press[0] == 1)
  {
    // Serial.println("Button pressed = RIGHT");
    line[lineNum].move_cursor_right();
  }
  else if (button_press[1] == 1)
  {
    // Serial.println("Button pressed = LEFT");
    line[lineNum].move_cursor_left();
  }
  else if (button_press[2] == 1)
  {
    // Serial.println("Button pressed = DOWN");
    if (!run_status)
    {
      line[lineNum].decrement_digit();
    }
  }
  else if (button_press[3] == 1)
  {
    // Serial.println("Button pressed = UP");
    if (!run_status)
    {
      line[lineNum].increment_digit();
    }
  }
  else if (button_press[4] == 1)
  {
    // Serial.println("Button pressed = SELECT");
    if (!run_status)
    {
      line[lineNum].deselect_line();
      lcd.setCursor(0, lineNum);
      lcd.print(line[lineNum].line);

      visited[lineNum] = false;
      lineNum = (lineNum + 1) % 3;
      line[lineNum].select_line();

      // Serial.println("LINE NUMBER = " + lineNum);
      // Serial.println(line[lineNum].line);
    }
  }
  else if (button_press[5] == 1)
  {
    // Serial.println("Button pressed = SET/RUN");
    run_status = 1 - run_status;
    // Serial.println(run_status);
    if (!run_status)
    {
      line[lineNum].select_line();
      line[0].encode_string();
      line[1].encode_string();
      line[2].encode_string();

      lcd.setCursor(0, 0);
      lcd.print(line[0].line);
      lcd.setCursor(0, 1);
      lcd.print(line[1].line);
      lcd.setCursor(0, 2);
      lcd.print(line[2].line);

      P = 2*line[0].get_parameter_value();
      I = 22*line[1].get_parameter_value();
      D = 2.8*line[2].get_parameter_value();
    }
    else
    {
      line[lineNum].deselect_line();
      line[0].decode_string();
      line[1].decode_string();
      line[2].decode_string();

      lcd.setCursor(0, 0);
      lcd.print(line[0].line);
      lcd.setCursor(0, 1);
      lcd.print(line[1].line);
      lcd.setCursor(0, 2);
      lcd.print(line[2].line);
      lcd.setCursor(0,3);
      lcd.print(" DIGITAL PID -> RUN ");

      // Serial.println(line[0].get_parameter_value(), 5);
      // Serial.println(line[1].get_parameter_value(), 5);
      // Serial.println(line[2].get_parameter_value(), 5);

      y1_new = 0;
      y1_old = 0;
      y2_new = 0;
      y2_old = 0;
      y3_new = 0;
      y3_old = 0;
      x_new = 0;
      x_old = 0;
      y_new = 0;
      y_old = 0;
      duty_cycle_new = 0;
      duty_cycle_old = 0;
      pid_output = 0;
      duty_cycle = 0;

      P = 2*line[0].get_parameter_value();
      I = 22*line[1].get_parameter_value();
      D = 2.8*line[2].get_parameter_value();
    }

  }
  else if (button_press[6] == 1)
  {
    // Serial.println("Button pressed = CLEAR");
    if (!run_status) {
      line[lineNum].clear_number();
    }
  }
  else if (button_press[7] == 1)
  {
    // Serial.println("Button pressed = AUTO");
  }

  if (!visited[lineNum] && !run_status)
  {
    visited[lineNum] = true;
    index = line[lineNum].cursor_position;
    modifiedLine = line[lineNum].line;
    modifiedLine[index] = ' ';
    presentState = 1;
    startTime = millis();
    lcd.setCursor(0, lineNum);
    lcd.print(' ');

    lcd.setCursor(0,3);
    lcd.print(" DIGITAL PID -> SET ");
  }

  if ( (millis() - startTime >= 500) )
  {
    index = line[lineNum].cursor_position;
    modifiedLine = line[lineNum].line;
    modifiedLine[index] = ' ';
    
    startTime = millis();
    presentState = 1 - presentState;
    if (presentState && !run_status)
    {
      lcd.setCursor(0, lineNum);
      lcd.print(modifiedLine);
      // Serial.println(modifiedLine);

      lcd.setCursor(0,3);
      lcd.print(" DIGITAL PID -> SET ");
    }
    else
    {
      if ((digitalRead(toggle_display) == HIGH) || !run_status)
      {
        // Serial.println(1);
        lcd.setCursor(0, lineNum);
        lcd.print(line[lineNum].line);
        lcd.setCursor(0,3);
        lcd.print(" DIGITAL PID -> SET ");
        // Serial.println(line[lineNum].line);
      }
      else 
      {
        // Serial.println(0);

      }
    }
  }

  // End

  memset(button_press, 0, sizeof(button_press));
  memcpy(previous_input, current_input, sizeof(current_input));

  
  input_signal_value = (analogRead(input_signal)*5.0)/1024.0;
  feedback_signal_value = (analogRead(feedback_signal)*5.0)/1024.0;
  // Serial.println(input_signal_value);
  if (round(input_signal_value) <= 10) {
    input_signal_MSB = " " + String(int(input_signal_value));
  } 
  else {
    input_signal_MSB = String(int(input_signal_value));
  }
  input_signal_LSB = String(round(100*(input_signal_value - int(input_signal_value))));
  
//  Serial.println(digitalRead(toggle_display));
//  if (digitalRead(toggle_display) == HIGH && run_status) {
//      lcd.setCursor(0, 0);
//      lcd.print("SET POINT  = " + input_signal_MSB + "." + input_signal_LSB + " V");
//      lcd.setCursor(0, 1);
//      lcd.print("                    ");
//      lcd.setCursor(0, 2);
//      lcd.print(setPointString);
//      lcd.setCursor(0, 3);
//      lcd.print("                    ");
//  }
//  else if (digitalRead(toggle_display) == LOW && run_status) {
//      lcd.setCursor(0, 0);
//      lcd.print(line[0].line);
//      lcd.setCursor(0, 1);
//      lcd.print(line[1].line);
//      lcd.setCursor(0, 2);
//      lcd.print(line[2].line);
//      lcd.setCursor(0, 3);
//      lcd.print(line3);
//  }

  // DIFFERENCE EQUATION
  pid_output = y_new;
  duty_cycle_new = (y_new + 2)*64;
  duty_cycle_new = min(255, max(0, duty_cycle_new));
  pwmWrite(pwm_output, duty_cycle_new);

    Serial.print(x_new);
    Serial.print(" ");
    Serial.println(y_new);
//
//    Serial.print(P);
//    Serial.print(" ");
//    Serial.println(I);
  
  if (micros() - startSamplingTime >= 1000000*Ts) {
    // Serial.println(startSamplingTime);
    val = analogRead(pid_signal_input);
    //  [0.06 0.01 0.0001] for 25 Hz
    //  [0.01 50 0] for 20 Hz
  
    x_new = (float(val)/1024.0)*V_level - 2.47;
    y1_new = P*x_new;
    y2_new = min(2, max(-2, y2_old)) + x_new*I*Ts;
    y3_new = y3_old*(1 - N*Ts) + D*N*(x_new - x_old);
    y_new = y1_new + y2_new + y3_new;

    x_old = x_new;
    y1_old = y1_new;
    y2_old = y2_new;
    y3_old = y3_new;
    y_old = y_new;

    startSamplingTime = micros();
  }
}

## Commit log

2019-11-20 Added circuit diagrams
    [Digital_PID.fzz]
2019-11-20 Added program + external libraries
    External Libraries:
    1. LiquidCrystal_I2C
    2. PWM
